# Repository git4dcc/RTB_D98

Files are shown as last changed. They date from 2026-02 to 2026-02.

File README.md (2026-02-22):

# RTB_D98




## This is a [opendcc](https://forum.opendcc.de/viewtopic.php?t=11034) forum project
The hard and software is based on the [D16](https://rtb4dcc.de/hardware/decoder/d16/) motor decoder. It implements a double-sided NEM-651 **function decoder** for use with DCC infrastructure. The hardware provides
- 10 auxiliary output ports
- up to 32 WS281x neo pixels

``Note: this repo is currently under construction and will be completed soon. (Feb 20, 2026)``

<details>
<summary>See also</summary>

- [RTB_D16 - NEM651](/../../../../git4dcc/RTB_D16)

</details>

<details>
<summary>User Guides</summary>

- User Guide - DE
- User Guide - EN

</details>

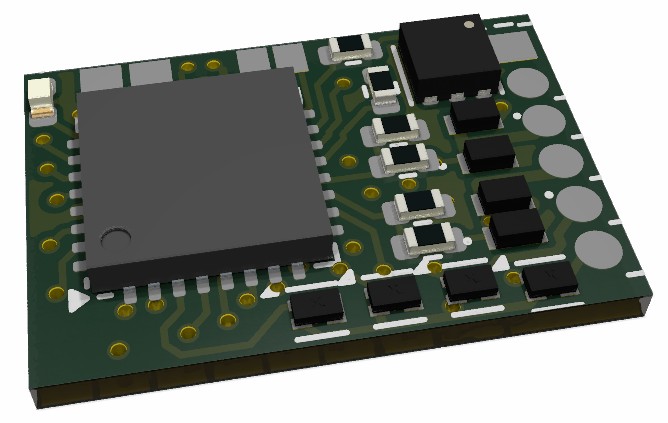
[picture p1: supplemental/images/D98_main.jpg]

<br>

The decoder has the following features,
- **NEM-651** connector
- **DCC**
  - DCC-A automatic logon
  - DCC-R protocol extension
  - Service Mode Programming
- **Railcom**
  - Channel 1/2
  - POM, xPOM, Long_1
  - DYN: QoS, Track-voltage, AUX-current, Temp, East/West
- double sided
- Dimension: 13 x 9 mm
- 5-20V track voltage
- heartbeat LED
- adjustable max AUX current (default 500mA)
- over temp protection
- **Function output**
  - LV/LR/AUX1/AUX2 open drain
  - AUX3/AUX4/AUX5/AUX6/AUX7/AUX8 logic level (5V)
  - LV/LR/AUX1/AUX2/AUX3/AUX4 (dimmable, 1.4kHz)
  - WS281x: up to 32 WS28xx neo pixels
- optional external buffer capacitor (max. 1500uF)
- <10mA idle power consumption
- Firmware update over main tracks via DCC-R protocol

# Hardware
The current PCB layout uses SMD footprints with 0.5mm pitch and mainly 0402 parts. Reflow soldering is recommended, handsoldering nearly impossible.

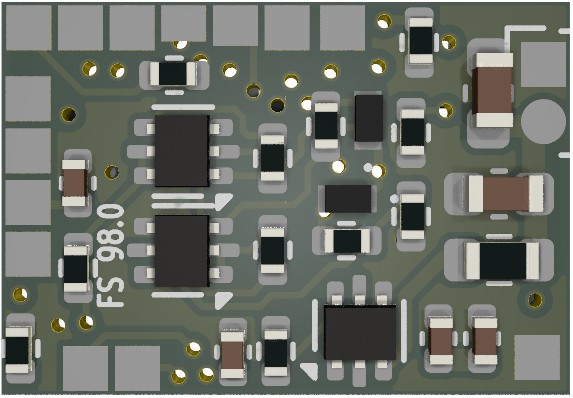
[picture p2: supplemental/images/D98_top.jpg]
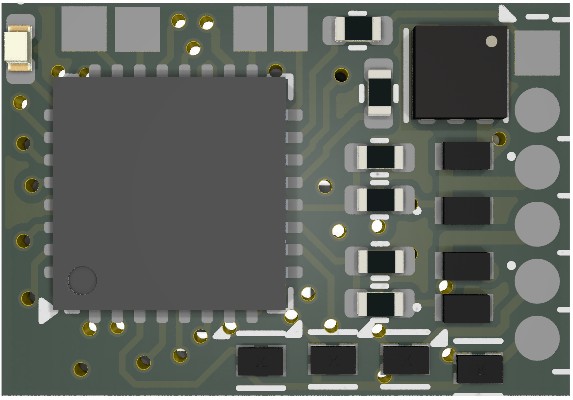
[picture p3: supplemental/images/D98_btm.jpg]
   

## PCB
- 6-layer PCB, FR4, 13 x 9 x 0.8mm (double sided)
- CPU: AVR64DA32
- Connector: NEM-651 (or solder)

## Kicad
[Schematic](doc/D98_schematic.pdf) | [Layout](doc/D98_layout.pdf) | [Gerber](gerber)

<details>
<summary>Dependency</summary>
<br>

:yellow_circle: Requires my Kicad project library [RTB_SamacSys](https://github.com/git4dcc/RTB_SamacSys) in the same directory tree.

</details>

## Firmware
Filename structure: { **pcb** }{ **code** }{ **version** }.hex

Example: **D98F0001**.hex

| | Description |
| --- | --- |
| **pcb** | Name of matching hardware (**D98**) |
| **code** | Type of code contained (**R**=rom, **B**=bootloader, **F**=flash, **U**=bld update, **P**=UPDI factory code) |
| **version** | Release version (**####**) |

[Firmware files](firmware)

# Images
| top | bottom |
| --- | --- |
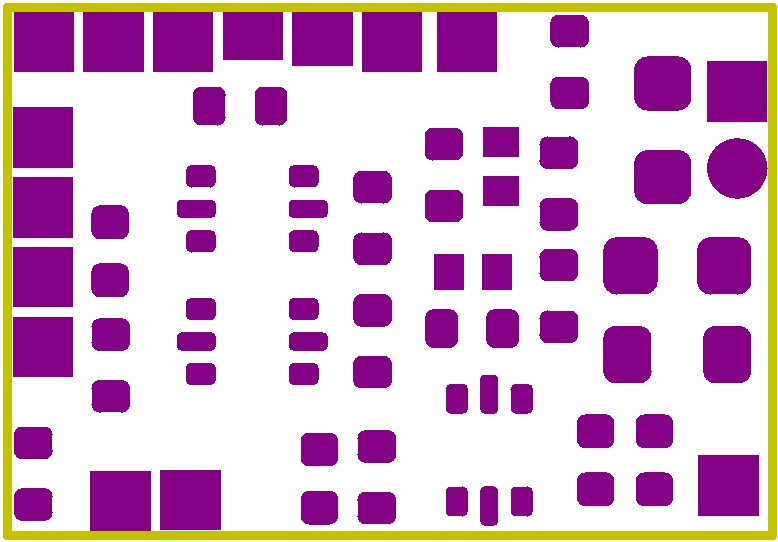
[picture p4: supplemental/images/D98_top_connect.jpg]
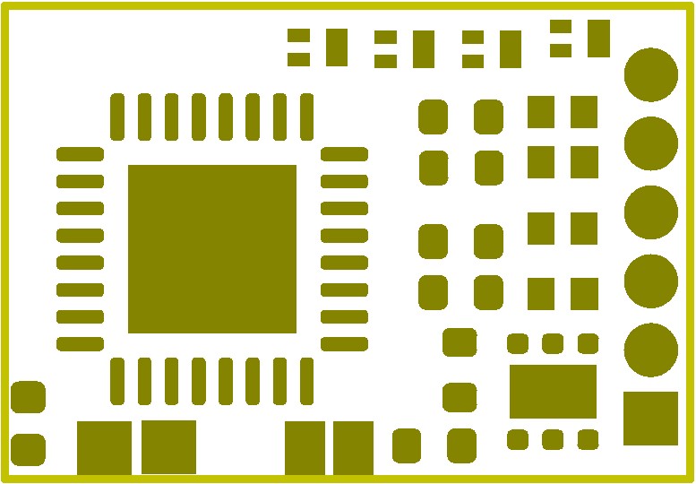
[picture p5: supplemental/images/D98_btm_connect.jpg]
|  |  |

# YouTube
Some YouTubes to see the D98 decoder in action.<br><br>

This project is intended for hobby use only and is distributed in accordance with the Apache License 2.0 agreement.

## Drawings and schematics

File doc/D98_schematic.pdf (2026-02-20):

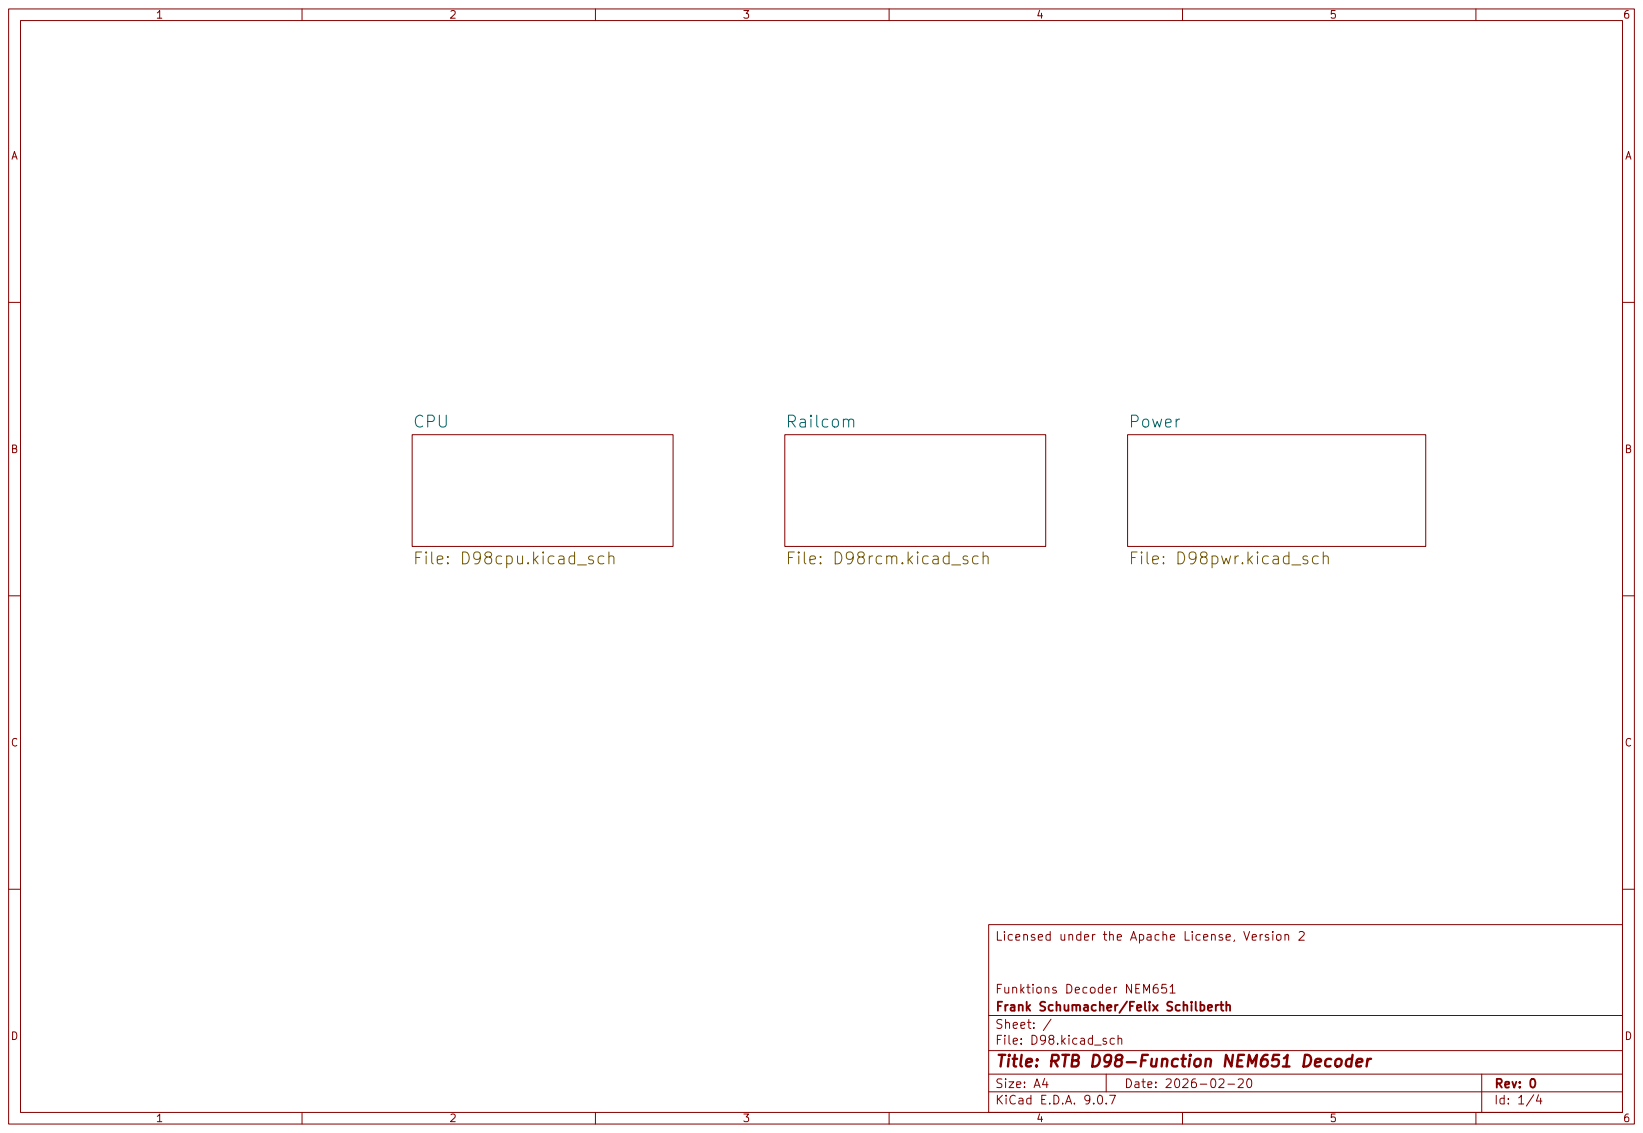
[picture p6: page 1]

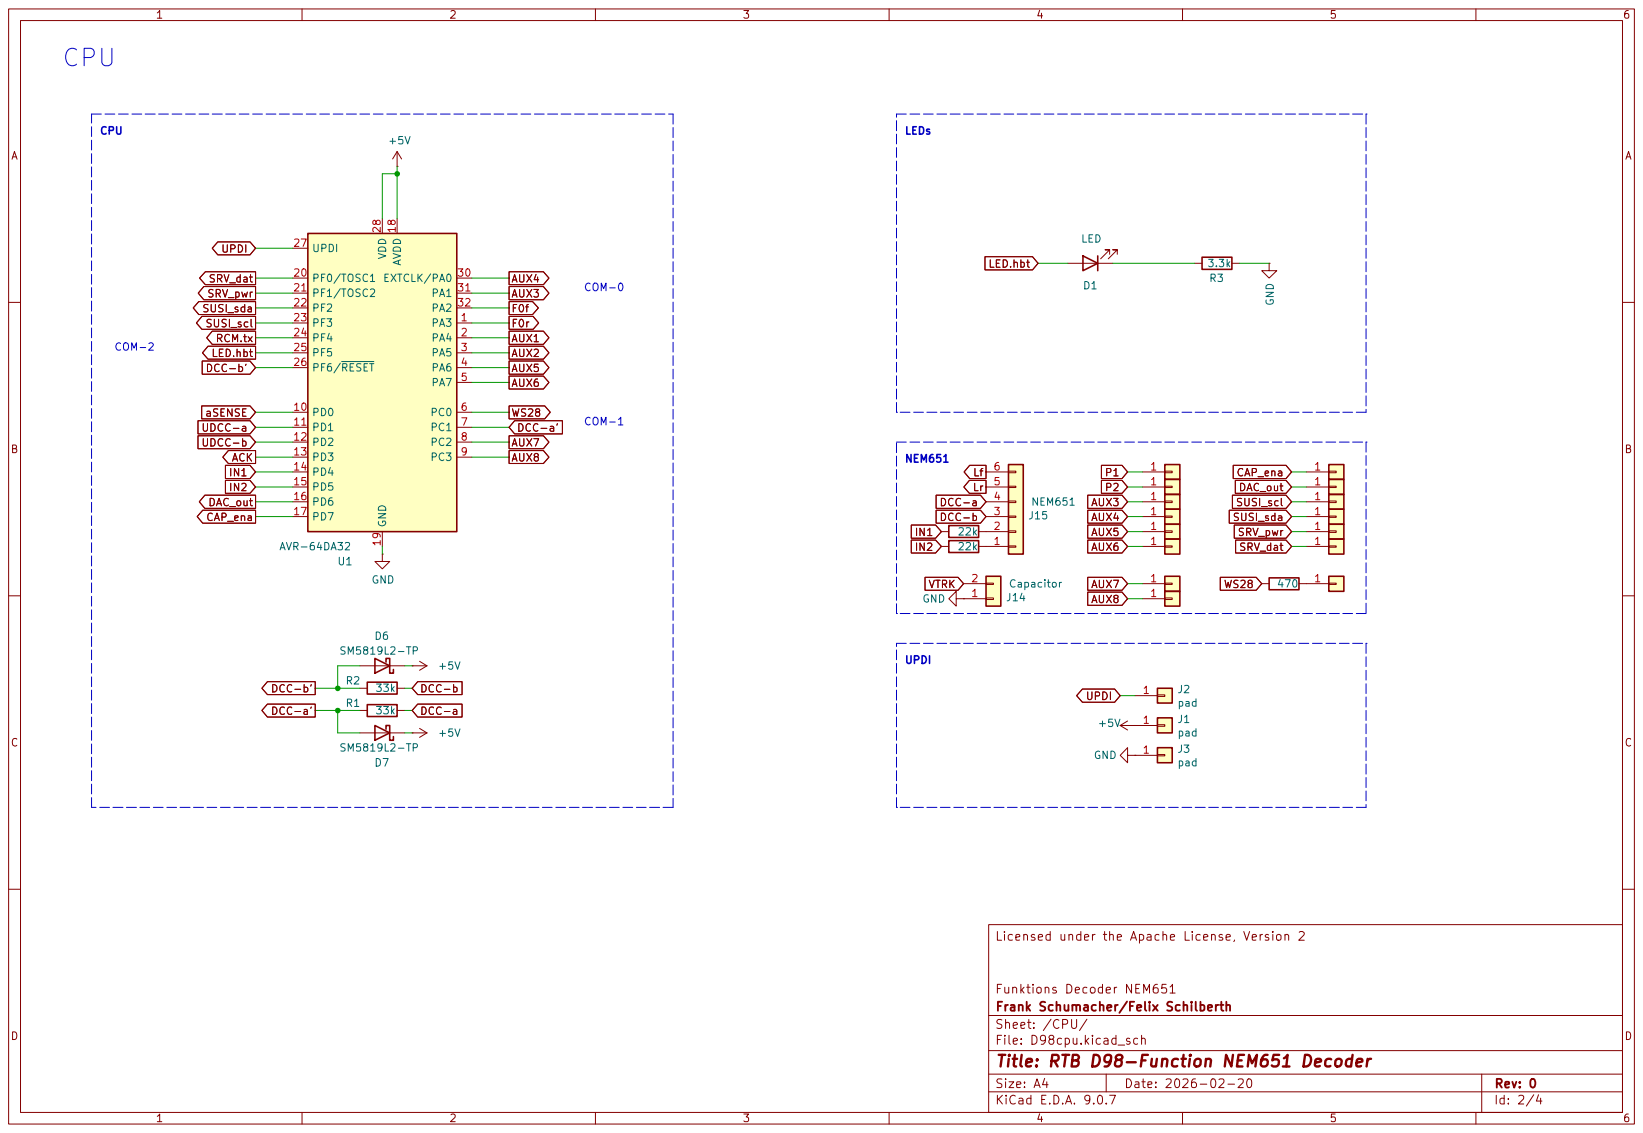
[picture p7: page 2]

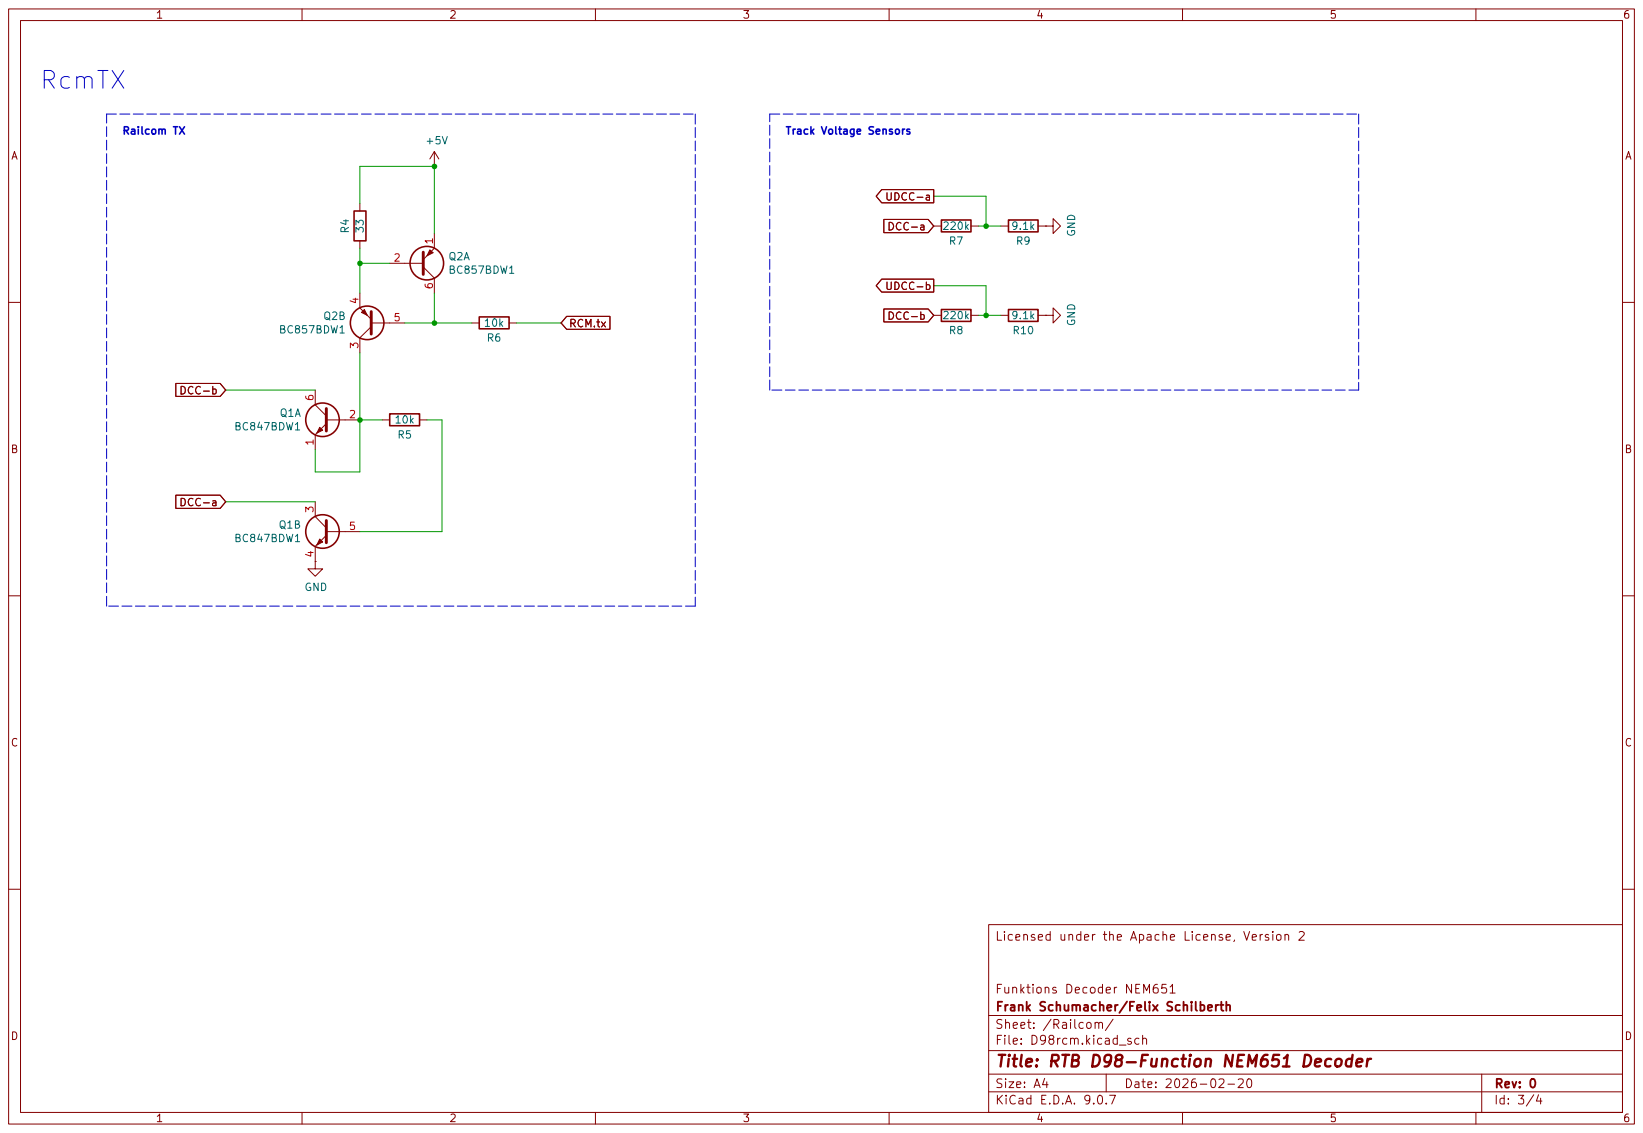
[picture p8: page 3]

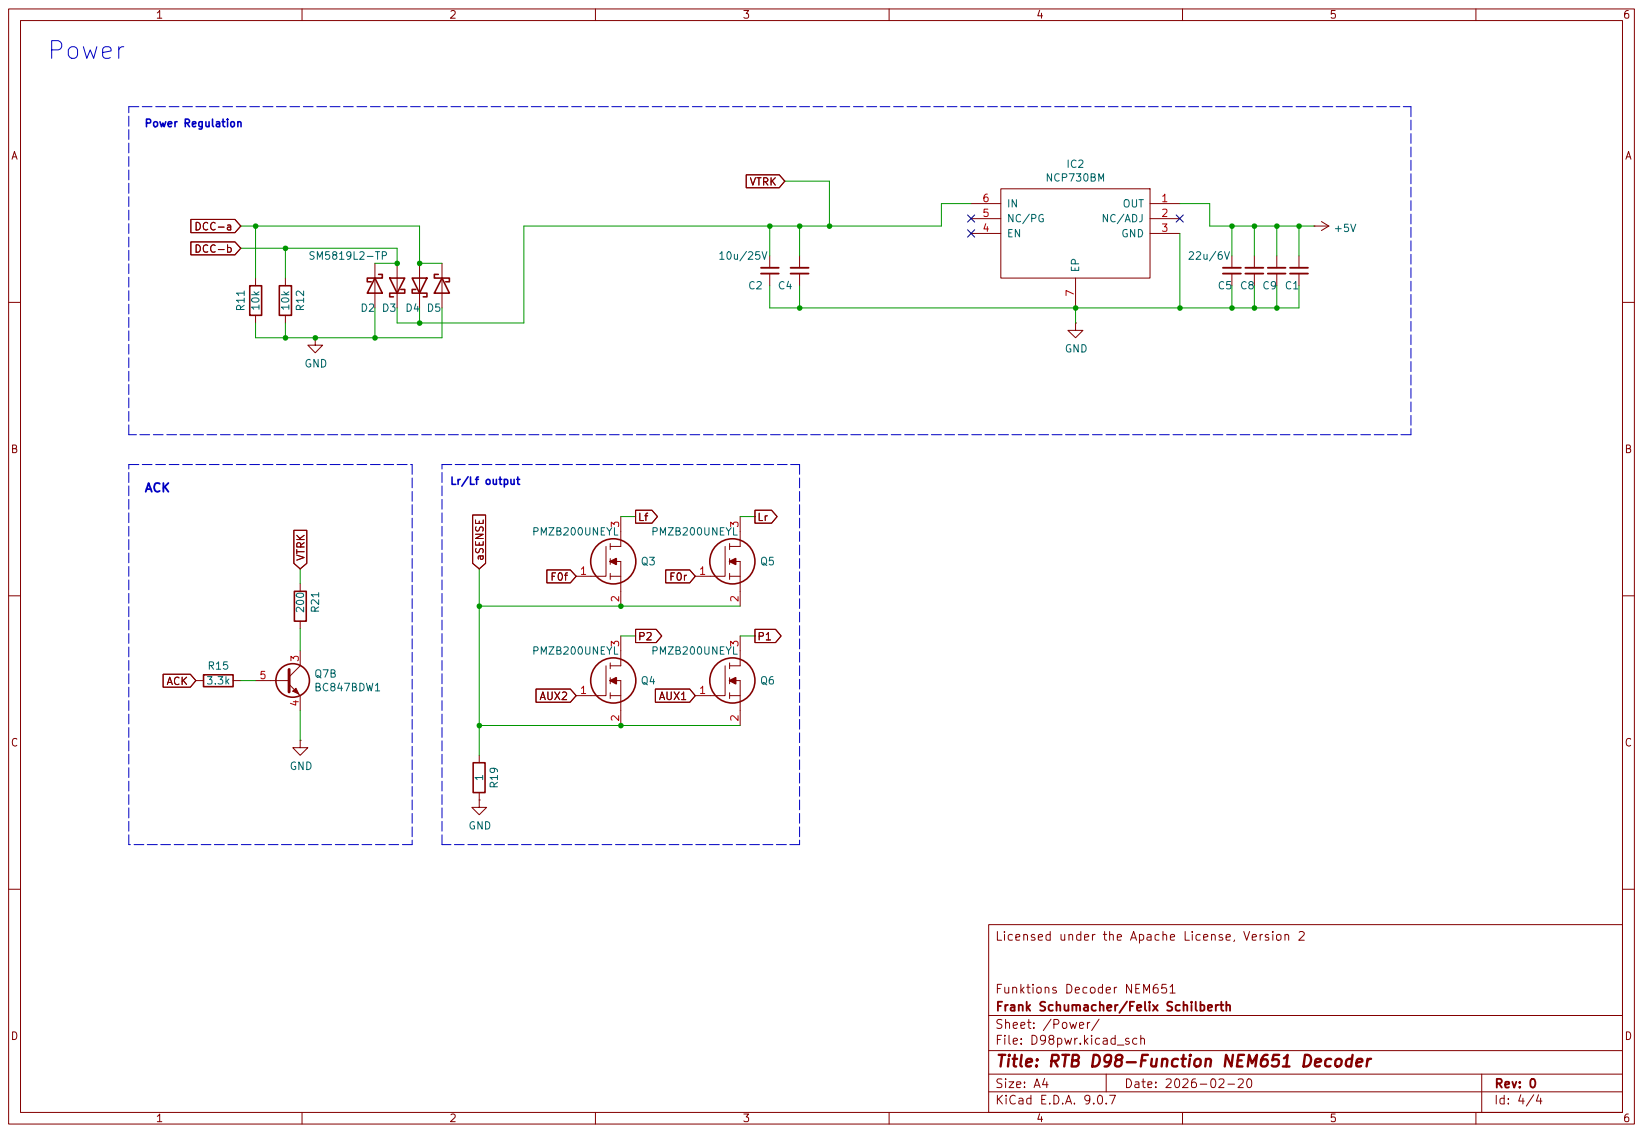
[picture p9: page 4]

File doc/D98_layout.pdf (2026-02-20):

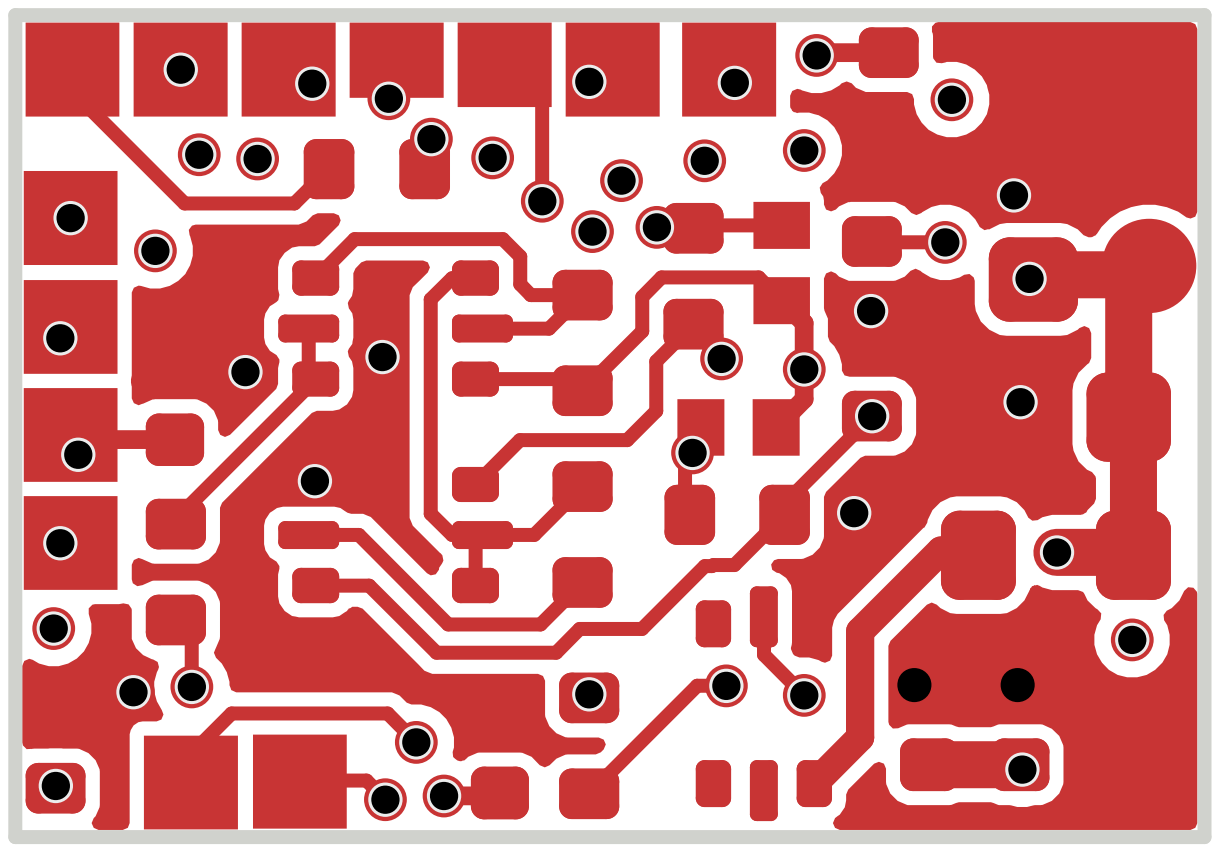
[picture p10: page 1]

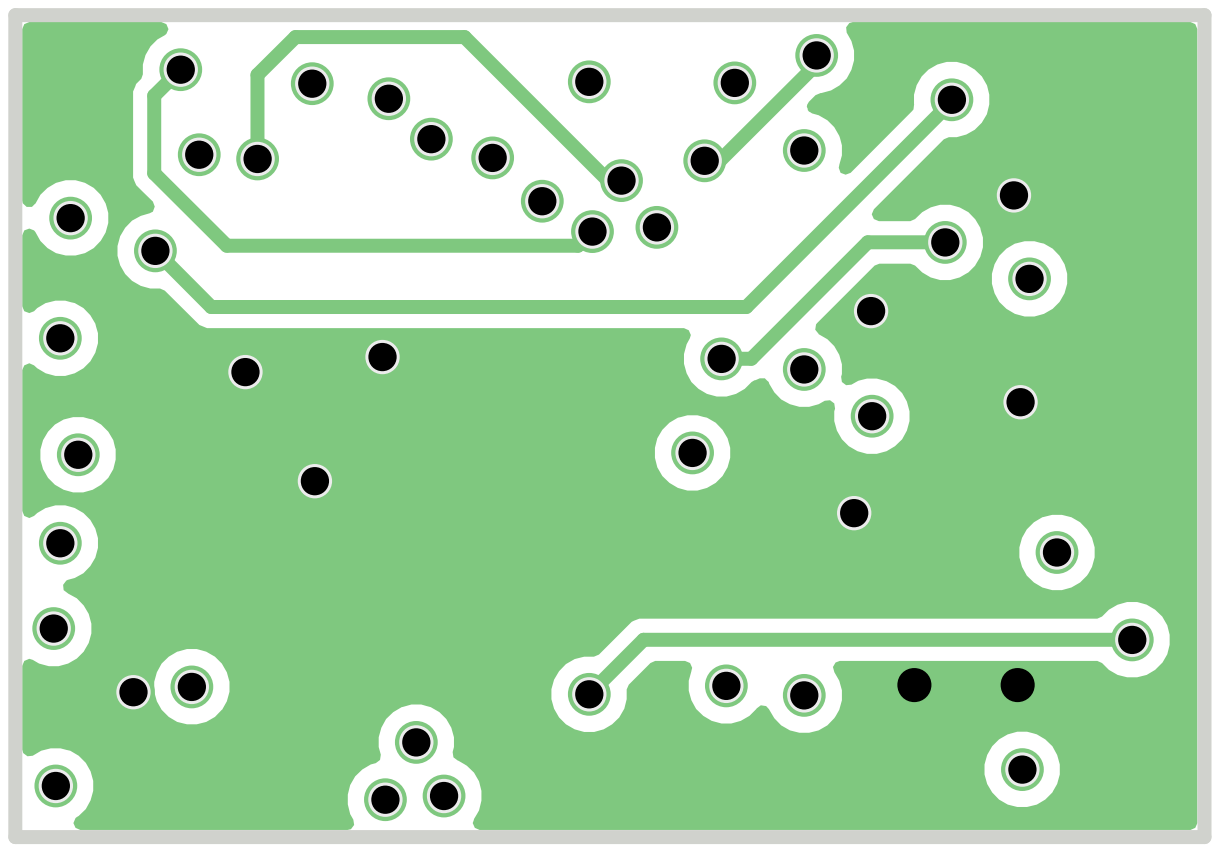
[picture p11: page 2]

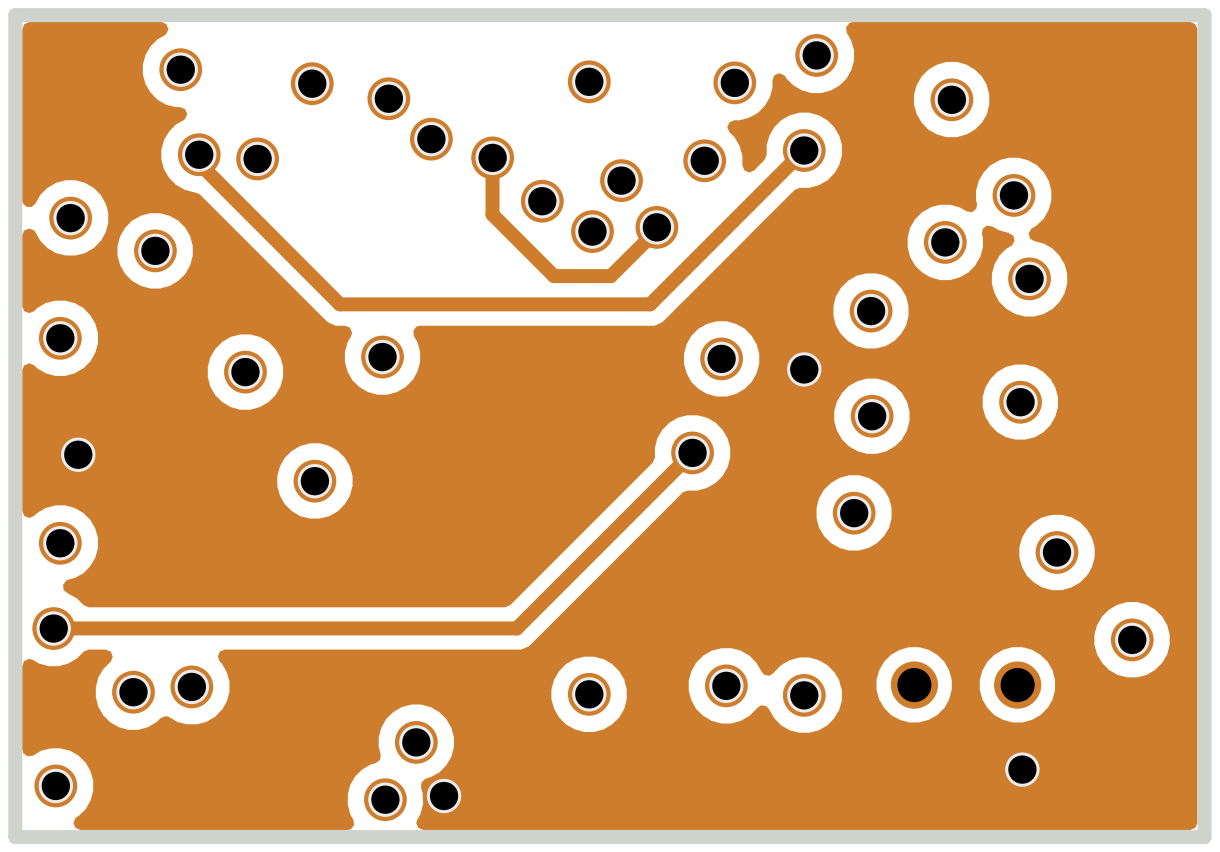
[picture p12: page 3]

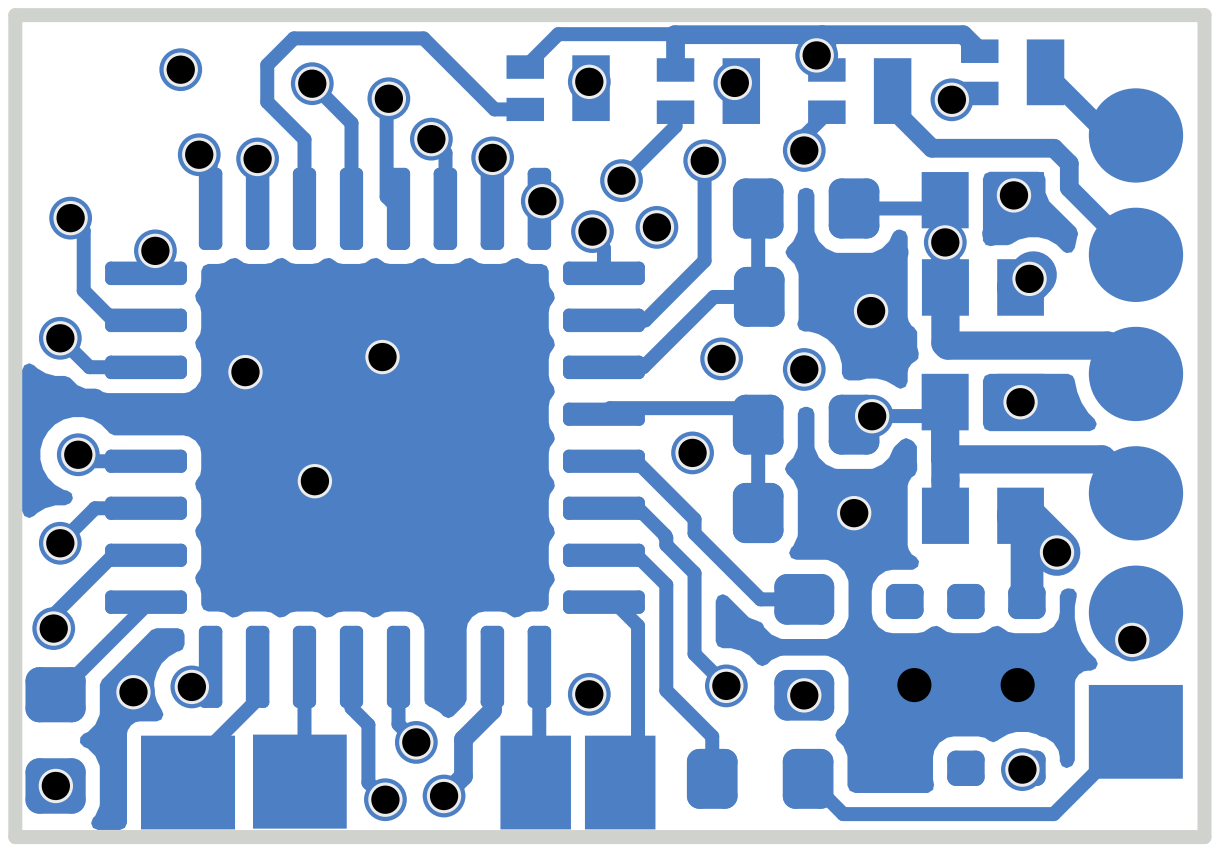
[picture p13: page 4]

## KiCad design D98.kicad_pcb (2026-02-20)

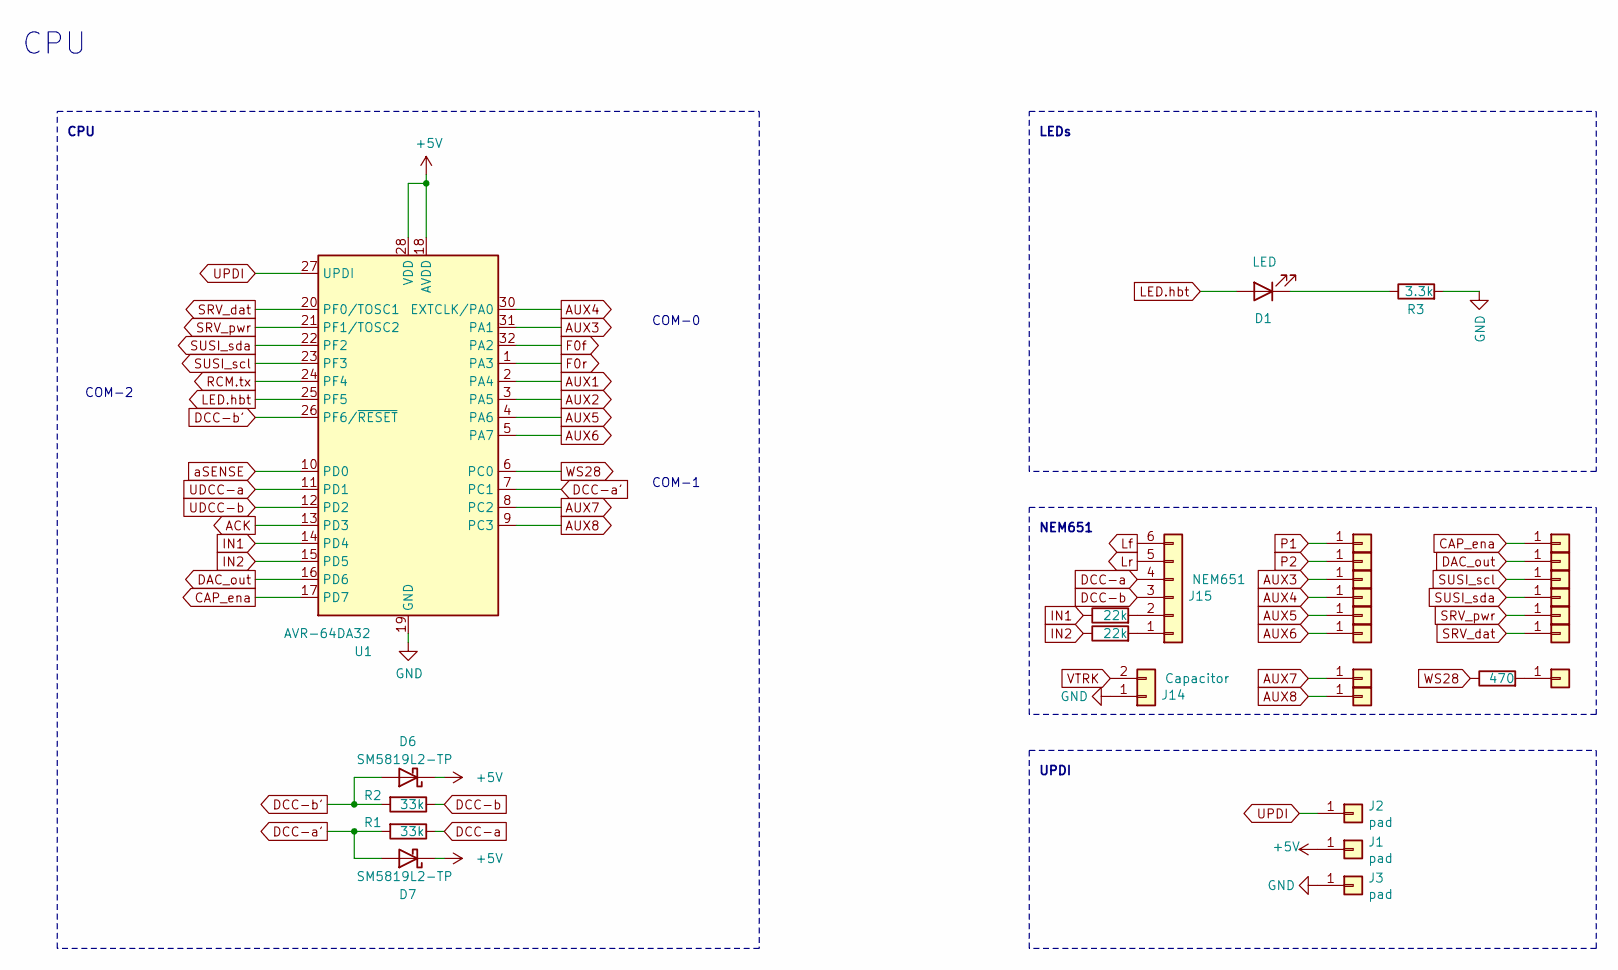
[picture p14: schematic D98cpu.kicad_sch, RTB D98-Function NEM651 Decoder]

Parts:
D1: LED; LED_0402_1005Metric
D6, D7: SM5819L2-TP; SM5819L2TP
J1, J2, J3, J6, J7, J8, J9, J10, J11, J12, J13, J16, J17, J18, J19, J20, J21, J22: pad; Solder_Pad_1x1mm
J14: Capacitor; PinHeader_1x02_P1.27mm_Horizontal
J15: NEM651; PinHeader_1x06_P1.27mm_Horizontal
R1, R2: 33k; R_0402_1005Metric
R3: 3.3k; R_0402_1005Metric
R13, R14: 22k; R_0402_1005Metric
R16: 470; R_0402_1005Metric
U1: AVR-64DA32; VQFN-32-1EP_5x5mm_P0.5mm_EP3.1x3.1mm

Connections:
+5V: D6.1 (K), D7.1 (K), J1.1, U1.18 (AVDD), U1.28 (VDD); also elsewhere on the board
ACK: U1.13 (PD3); also elsewhere on the board
AUX1: U1.2 (PA4); also elsewhere on the board
AUX2: U1.3 (PA5); also elsewhere on the board
AUX3: J17.1, U1.31 (PA1)
AUX4: J12.1, U1.30 (EXTCLK/PA0)
AUX5: J19.1, U1.4 (PA6)
AUX6: J11.1, U1.5 (PA7)
AUX7: J20.1, U1.8 (PC2)
AUX8: J21.1, U1.9 (PC3)
CAP_ena: J13.1, U1.17 (PD7)
DAC_out: J7.1, U1.16 (PD6)
DCC-a: J15.4, R1.1; also elsewhere on the board
DCC-a': D7.2 (A), R1.2, U1.7 (PC1)
DCC-b: J15.3, R2.1; also elsewhere on the board
DCC-b': D6.2 (A), R2.2, U1.26 (PF6/~RESET)
F0f: U1.32 (PA2); also elsewhere on the board
F0r: U1.1 (PA3); also elsewhere on the board
GND: J3.1, J14.1, R3.2, U1.19 (GND), U1.29 (GND), U1.33 (GND); also elsewhere on the board
IN1: R13.1, U1.14 (PD4)
IN2: R14.1, U1.15 (PD5)
LED.hbt: D1.2 (A), U1.25 (PF5)
Lf: J15.6; also elsewhere on the board
Lr: J15.5; also elsewhere on the board
unnamed: D1.1 (K), R3.1
unnamed: J15.1, R14.2
unnamed: J15.2, R13.2
unnamed: J22.1, R16.2
P1: J8.1; also elsewhere on the board
P2: J9.1; also elsewhere on the board
RCM.tx: U1.24 (PF4); also elsewhere on the board
SRV_dat: J18.1, U1.20 (PF0/TOSC1)
SRV_pwr: J16.1, U1.21 (PF1/TOSC2)
SUSI_scl: J6.1, U1.23 (PF3)
SUSI_sda: J10.1, U1.22 (PF2)
UDCC-a: U1.11 (PD1); also elsewhere on the board
UDCC-b: U1.12 (PD2); also elsewhere on the board
UPDI: J2.1, U1.27 (UPDI)
VTRK: J14.2; also elsewhere on the board
WS28: R16.1, U1.6 (PC0)
aSENSE: U1.10 (PD0); also elsewhere on the board

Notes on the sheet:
UPDI
COM-2
COM-0
CPU
NEM651
LEDs
COM-1

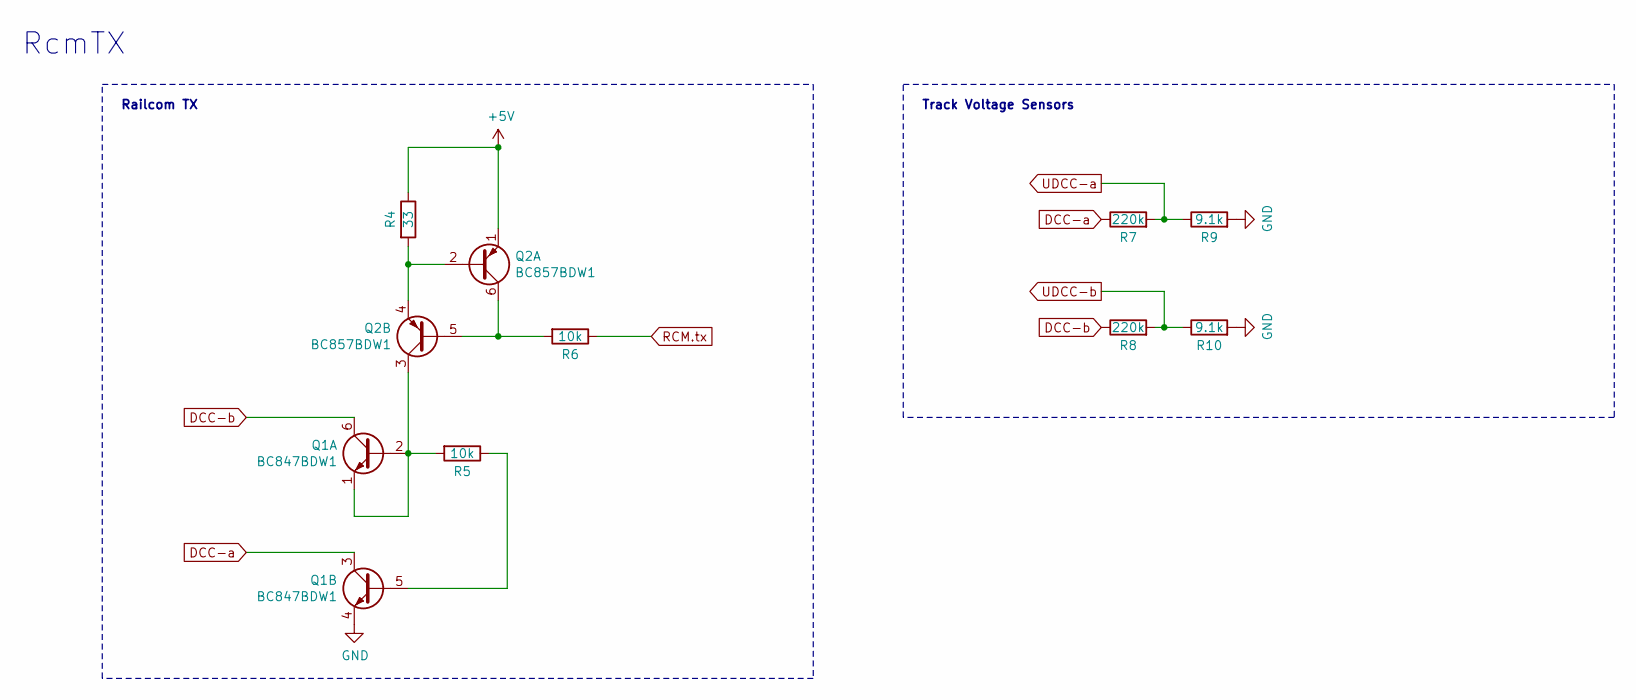
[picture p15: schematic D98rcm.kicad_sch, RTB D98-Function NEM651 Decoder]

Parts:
Q1: BC847BDW1; SOT-666
Q2: BC857BDW1; SOT-666
R4: 33; R_0402_1005Metric
R5, R6: 10k; R_0402_1005Metric
R7, R8: 220k; R_0402_1005Metric
R9, R10: 9.1k; R_0402_1005Metric

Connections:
+5V: Q2.1 (E1), R4.1; also elsewhere on the board
DCC-a: Q1.3 (C2), R7.1; also elsewhere on the board
DCC-b: Q1.6 (C1), R8.1; also elsewhere on the board
GND: Q1.4 (E2), R9.2, R10.2; also elsewhere on the board
unnamed: Q1.1 (E1), Q1.2 (B1), Q2.3 (C2), R5.2
unnamed: Q1.5 (B2), R5.1
unnamed: Q2.2 (B1), Q2.4 (E2), R4.2
unnamed: Q2.5 (B2), Q2.6 (C1), R6.2
RCM.tx: R6.1; also elsewhere on the board
UDCC-a: R7.2, R9.1; also elsewhere on the board
UDCC-b: R8.2, R10.1; also elsewhere on the board

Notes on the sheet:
Railcom TX
Track Voltage Sensors
RcmTX

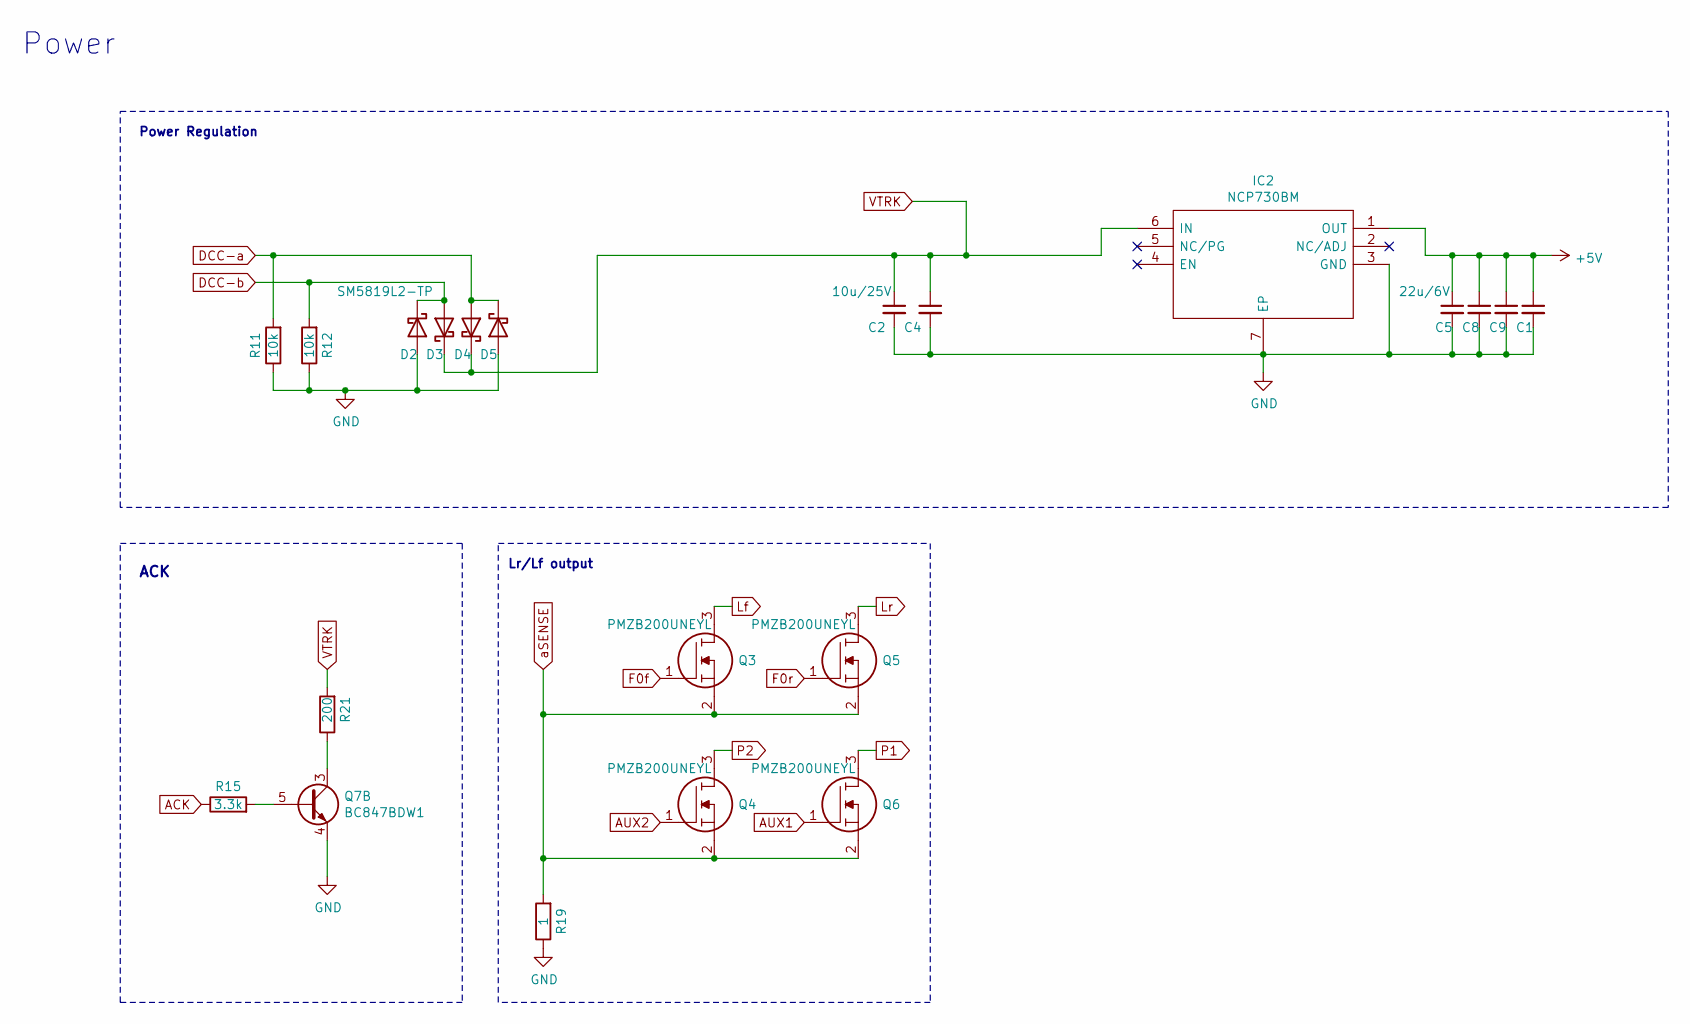
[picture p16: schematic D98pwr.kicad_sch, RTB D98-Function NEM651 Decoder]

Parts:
C1, C5, C8, C9: 22u/6V; C_0402_1005Metric
C2, C4: 10u/25V; C_0603_1608Metric
D2, D3, D4, D5: SM5819L2-TP; SM5819L2TP
IC2: NCP730BM; WSON-6-1EP_2x2mm_P0.65mm_EP1x1.6mm_ThermalVias; Mouser Part Number 863-NCP730BMT330TBG
Q3, Q4, Q5, Q6: PMZB200UNEYL; Diodes_DFN1006-3; Mouser Part Number 771-PMZB200UNEYL
Q7: BC847BDW1; SOT-666
R11, R12: 10k; R_0402_1005Metric
R15: 3.3k; R_0402_1005Metric; JLCPCB C25890
R19: 1; R_0402_1005Metric
R21: 200; R_0603_1608Metric; JLCPCB C8218

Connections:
+5V: C1.1, C5.1, C8.1, C9.1, IC2.1 (OUT); also elsewhere on the board
ACK: R15.1; also elsewhere on the board
AUX1: Q6.1; also elsewhere on the board
AUX2: Q4.1; also elsewhere on the board
DCC-a: D4.2 (A), D5.1 (K), R11.2; also elsewhere on the board
DCC-b: D2.1 (K), D3.2 (A), R12.2; also elsewhere on the board
F0f: Q3.1; also elsewhere on the board
F0r: Q5.1; also elsewhere on the board
GND: C1.2, C2.2, C4.2, C5.2, C8.2, C9.2, D2.2 (A), D5.2 (A), IC2.3 (GND), IC2.7 (EP), Q7.4 (E2), R11.1, R12.1, R19.1; also elsewhere on the board
Lf: Q3.3; also elsewhere on the board
Lr: Q5.3; also elsewhere on the board
unnamed: Q7.5 (B2), R15.2
unnamed: Q7.3 (C2), R21.1
P1: Q6.3; also elsewhere on the board
P2: Q4.3; also elsewhere on the board
VTRK: C2.1, C4.1, D3.1 (K), D4.1 (K), IC2.6 (IN), R21.2; also elsewhere on the board
aSENSE: Q3.2, Q4.2, Q5.2, Q6.2, R19.2; also elsewhere on the board

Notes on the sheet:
ACK
Lr/Lf output
Power
Power Regulation

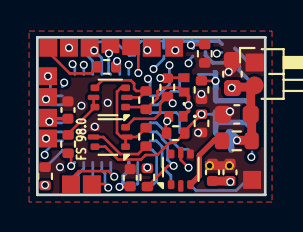
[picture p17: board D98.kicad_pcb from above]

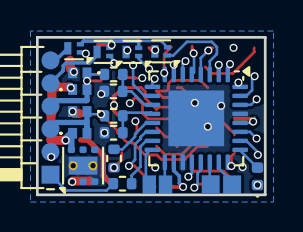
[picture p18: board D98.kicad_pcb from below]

Board: 4 copper layers, 12.7 x 8.8 mm, 60 parts (22 on the bottom side), 47 nets.

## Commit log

2026-02-20 Revise README for Railcom and WS28xx details
    Updated features and specifications for clarity.
2026-02-20 Revise function output details in README
    Updated function output specifications for clarity and corrected AUX3-AUX8 logic level voltage.

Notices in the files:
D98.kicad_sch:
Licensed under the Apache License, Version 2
